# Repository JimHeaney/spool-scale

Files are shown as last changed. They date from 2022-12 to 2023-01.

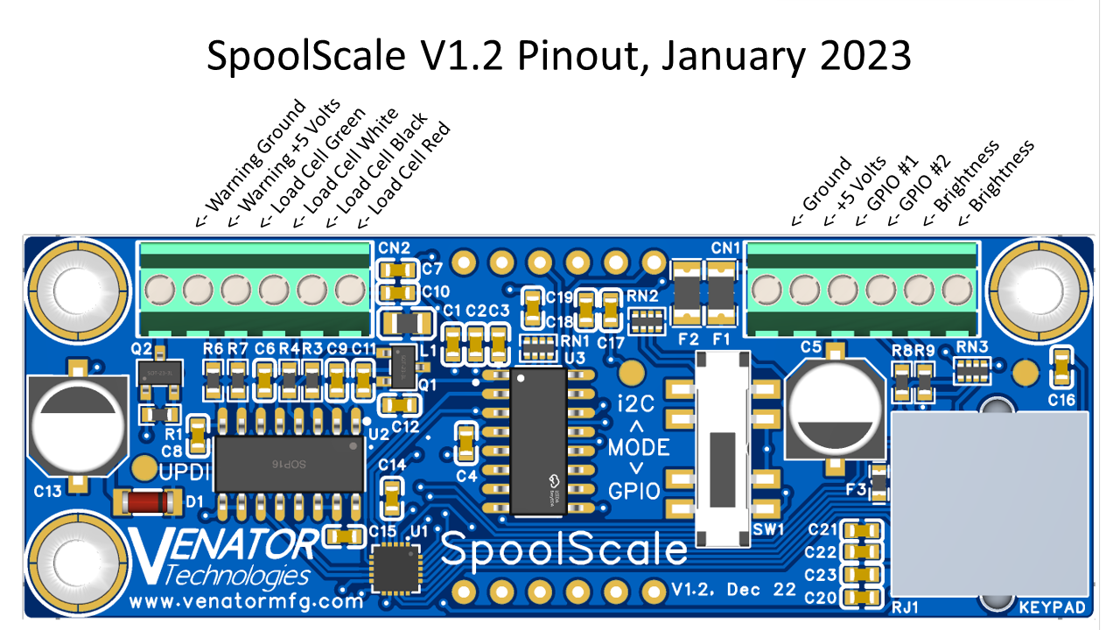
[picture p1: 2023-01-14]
Core/SpoolScale Pinout.png

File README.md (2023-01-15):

# SpoolScale

## Summary
Have you ever run out of filament mid-print? The SpoolScale is a simple add-on device for any 3D printer that allows you to precisely know how much filament is left on your spool. The SpoolScale can be integrated with any style 3D printer and spool holder, and can be connected to any wheatstone bridge load cell. Additional functionality can be unlocked by connecting the SpoolScale to a 3D printer directly via GPIO, i2C, or UART. 

### More information can be found on the [GitHub Wiki](https://github.com/JimHeaney/spool-scale/wiki).

## Current Release
There are no stable versions for release. The latest WIP is Version 1.1

## Current State
The SpoolScale is currently being developed to Version 1.2.

## What's New

[Read More on the Version Information page!](https://github.com/JimHeaney/spool-scale/wiki/Version-Information)

Version 1.2 will likely be the first stable release of the SpoolScale. Version 1.1 was used as a proof of concept and for small-scale field testing. A number of bugs were immediately identified, and a number of other improvements will be made based on user feedback. These include:
* Removing DIP switch configuration, instead adding RJ11 port for connecting an i2C keypad. 
  * This will allow for more versatile configuration, including typing in spool weights directly, saving/loading 4 "favorite" spool weights, etc. 
  * All of these settings will be exposed as i2C slave registers, so the keypad is not needed if using the SpoolScale as an i2C device. 
* Added more robust switch for selecting SpoolScale mode 
  * Removed UART mode, options are now GPIO, standalone, and i2C.
* Redid layout of PCB, removed secondary AtTiny footprint
* General component optimization, layout improvements, etc. 

Future Proposed Changes:
* Change 6P6C RJ12 to more common 6P4C RJ11 (remove plug detection)

## Instructions & Further Documentation
[See the wiki on GitHub!](https://github.com/JimHeaney/SpoolScale/wiki) 

## Photos & Media


## Support Me
You can buy me a coffee [here](https://www.buymeacoffee.com/jimheaney)!

## License
This project is licensed under the Creative Commons 4.0 Attribution-NonCommercial-ShareAlike. For more information, click [here](https://creativecommons.org/licenses/by-nc-sa/4.0/).

If you are interested in using this project under a different license (e.g. for commercial use), please contact me.

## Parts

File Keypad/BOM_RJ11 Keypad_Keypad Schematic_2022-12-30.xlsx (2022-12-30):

No. | Quantity | Device | Designator | Footprint | Value | Manufacturer Part | Manufacturer | Supplier Part | Supplier
1 | 2 | CC0603KRX7R9BB104 | C1,C3 | C0603 | 100nF | CC0603KRX7R9BB104 | YAGEO(国巨) | C14663 | LCSC
2 | 2 | CL10A106MA8NRNC | C2,C4 | C0603 | 10uF | CL10A106MA8NRNC | SAMSUNG(三星) | C96446 | LCSC
3 | 1 | BSMD0603-001-60V | F3 | F0603 |  | BSMD0603-001-60V | BHFUSE(佰宏) | C914088 | LCSC
4 | 1 | PH-00779 | H1 | HDR-TH_10P-P2.54-V-M |  | PH-00779 | Liansheng(连盛) | C2685184 | LCSC
5 | 2 | SMTSO3030CTJ | N1,N2 | SMD_BD5.6-D4.1 |  | SMTSO3030CTJ | Sinhoo(雄和远景) | C2915308 | LCSC
6 | 4 | 0603WAF2001T5E | R1,R2,R3,R4 | R0603 | 2kΩ | 0603WAF2001T5E | UNI-ROYAL(厚声) | C22975 | LCSC
7 | 1 | R-RJ11R06P-A801 | RJ1 | RJ11-TH_PCB-6P6C-90 |  | R-RJ11R06P-A801 | Ckmtw(灿科盟) | C189747 | LCSC
8 | 1 | 4D02WGJ0103TCE | RN1 | RES-ARRAY-SMD_0402-8P-L2.0-W1.0-BL | 10kΩ | 4D02WGJ0103TCE | UNI-ROYAL(厚声) | C25725 | LCSC
9 | 1 | PCA9557PW,118 | U1 | TSSOP-16_L5.0-W4.4-P0.65-LS6.4-BL |  | PCA9557PW,118 | NXP(恩智浦) | C141380 | LCSC

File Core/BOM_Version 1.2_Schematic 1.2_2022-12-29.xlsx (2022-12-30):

No. | Quantity | Device | Designator | Footprint | Value | Manufacturer Part | Manufacturer | Supplier Part | Supplier
1 | 3 | CL10C101JB8NNNC | C1,C2,C3 | C0603 | 100pF | CL10C101JB8NNNC | SAMSUNG(三星) | C14858 | LCSC
2 | 11 | CC0603KRX7R9BB104 | C4,C6,C7,C8,C9,C12,C14,C16,C18,C20,C22 | C0603 | 100nF | CC0603KRX7R9BB104 | YAGEO(国巨) | C14663 | LCSC
3 | 2 | VT1V101M0607 | C5,C13 | CAP-SMD_BD6.3-L6.6-W6.6-FD | 100uF | VT1V101M0607 | ROQANG(容强) | C141427 | LCSC
4 | 7 | CL10A106MA8NRNC | C10,C11,C15,C17,C19,C21,C23 | C0603 | 10uF | CL10A106MA8NRNC | SAMSUNG(三星) | C96446 | LCSC
5 | 2 | DB125-2.54-6P-GN | CN1,CN2 | CONN-TH_DB125-2.54-6P-GN |  | DB125-2.54-6P-GN | DIBO(地博电气) | C918124 | LCSC
6 | 1 | ZMM5V6-M | D1 | LL-34_L3.5-W1.5-RD |  | ZMM5V6-M | ST(先科) | C8062 | LCSC
7 | 2 | JK-nSMD100/16V | F1,F2 | F1206 |  | JK-nSMD100/16V | JK(金科) | C2830246 | LCSC
8 | 1 | BSMD0603-001-60V | F3 | F0603 |  | BSMD0603-001-60V | BHFUSE(佰宏) | C914088 | LCSC
9 | 1 | CMI201209U2R2KT | L1 | L0805 | 2.2uH | CMI201209U2R2KT | FH(风华) | C1043 | LCSC
10 | 1 | SR440801N/32 | LED1 | LED-SEG-TH_12P-L71.6-W25.7-P2.54-S22.00-BL |  | SR440801N/32 | 方舟 ARKLED | C252230 | LCSC
11 | 3 | SMTSO3030CTJ | N1,N2,N3 | SMD_BD5.6-D4.1 |  | SMTSO3030CTJ | Sinhoo(雄和远景) | C2915308 | LCSC
12 | 1 | S8550 | Q1 | SOT-23-3_L2.9-W1.6-P1.90-LS2.8-BR |  | S8550 | CJ（江苏长电/长晶） | C105432 | LCSC
13 | 1 | AO3400A_C20917 | Q2 | SOT-23-3_L2.9-W1.6-P1.90-LS2.8-BR |  | AO3400A | AOS | C20917 | LCSC
14 | 2 | 0603WAF2002T5E | R1,R3 | R0603 | 20kΩ | 0603WAF2002T5E | UNI-ROYAL(厚声) | C4184 | LCSC
15 | 1 | 0603WAF8201T5E | R4 | R0603 | 8.2kΩ | 0603WAF8201T5E | UNI-ROYAL(厚声) | C25981 | LCSC
16 | 2 | 0603WAF1000T5E | R6,R7 | R0603 |  | 0603WAF1000T5E | UNI-ROYAL(厚声) | C22775 | LCSC
17 | 2 | 0603WAF2200T5E | R8,R9 | R0603 |  | 0603WAF2200T5E | UNI-ROYAL(厚声) | C22962 | LCSC
18 | 1 | R-RJ11R06P-A801 | RJ1 | RJ11-TH_PCB-6P6C-90 |  | R-RJ11R06P-A801 | Ckmtw(灿科盟) | C189747 | LCSC
19 | 3 | 4D02WGJ0103TCE | RN1,RN2,RN3 | RES-ARRAY-SMD_0402-8P-L2.0-W1.0-BL | 10kΩ | 4D02WGJ0103TCE | UNI-ROYAL(厚声) | C25725 | LCSC
20 | 1 | K3-2336S-K1 | SW1 | SW-SMD_K3-2336S-K1 |  | K3-2336S-K1 | 韩国韩荣 | C145840 | LCSC
21 | 1 | ATTINY1616-MNR | U1 | QFN-20_L3.0-W3.0-P0.40-BL-EP1.7 |  | ATTINY1616-MNR | MICROCHIP(美国微芯) | C507118 | LCSC
22 | 1 | HX711 | U2 | SOP-16_L10.0-W3.9-P1.27-LS6.0-BL |  | HX711 | AVIA(海芯科技) | C43656 | LCSC
23 | 1 | TM1616 | U3 | SOIC-16_L9.9-W3.9-P1.27-LS6.0-BL |  | TM1616 | TM(天微) | C51000 | LCSC

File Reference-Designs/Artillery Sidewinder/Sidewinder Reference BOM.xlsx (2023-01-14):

SpoolScale Artillery Sidewinder X1 Reference Design
Bill of Materials, V1.1, Jan 2023
https://github.com/JimHeaney/spool-scale/wiki/Reference-Designs#artillery-sidewinder-x1
Number | Name | Quantity | Source | Link | Notes
1 | SpoolScale | 1 | Tindie | https://www.tindie.com/products/jimheaney/spoolscale/
2 | Load Cell - 5kg | 2 | Adafruit | https://www.adafruit.com/product/4541 | Can also be purchased with SpoolScale
3 | 4-Wire Cable | 1 | Amazon | https://www.amazon.com/gp/product/B08JTZCJV1/ref=ppx_yo_dt_b_search_asin_title?ie=UTF8&psc=1 | Need appx. 1 meter
4 | Interface Mount | 1 | Printed
5 | Load Cell Mount | 2 | Printed
6 | Load Cell Spacer | 4 | Printed
7 | Spool Mount Adapter | 2 | Printed
8 | Spool Spacer | 2 | Printed
9 | M4 T Nut | 4 | Amazon | https://www.amazon.com/gp/product/B07FPLZXTF/ref=ppx_yo_dt_b_search_asin_title?ie=UTF8&psc=1 | Large kit, can be used for other T-nuts
10 | M5 T Nut | 2 | Amazon | https://www.amazon.com/gp/product/B07FPLZXTF/ref=ppx_yo_dt_b_search_asin_title?ie=UTF8&psc=1 | Can be had from same kit as M4
11 | M5 Hex Nut | 4 | McMaster-Carr | https://www.mcmaster.com/90591A260/ | Can use M5 T Nuts instead
12 | M5x12 Countersunk | 2 | McMaster-Carr | https://www.mcmaster.com/91294A210/
13 | M5x18 Countersunk | 4 | McMaster-Carr | https://www.mcmaster.com/91294A213/
14 | M4x12 Socket Head | 4 | McMaster-Carr | https://www.mcmaster.com/91294A192/
15 | M4x12 Countersunk | 8 | McMaster-Carr | https://www.mcmaster.com/91294A192/
16 | M3x16 Countersunk | 3 | McMaster-Carr | https://www.mcmaster.com/91294A134/

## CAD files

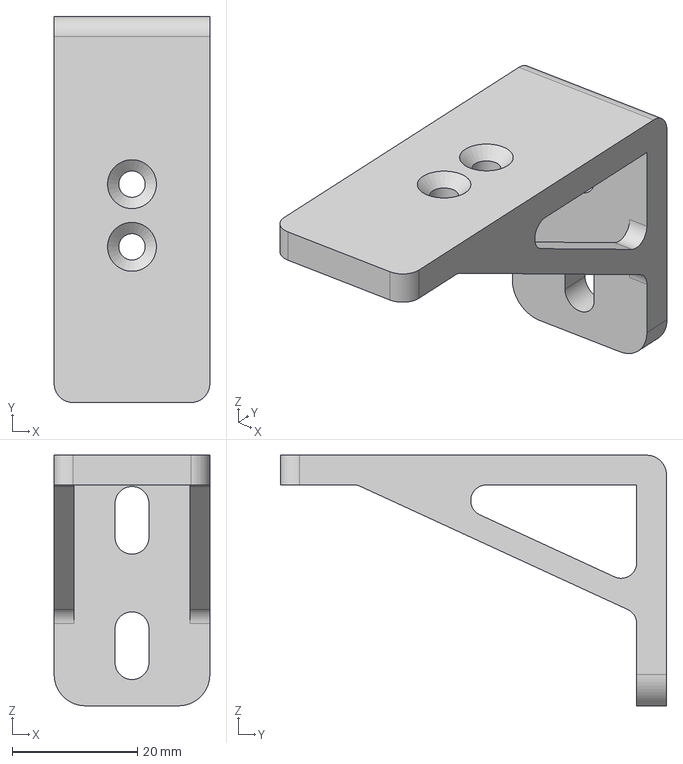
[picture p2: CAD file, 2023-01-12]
Reference-Designs/Artillery Sidewinder/Spool Mount Adapter.step
24.9 x 61.6 x 40.0 mm

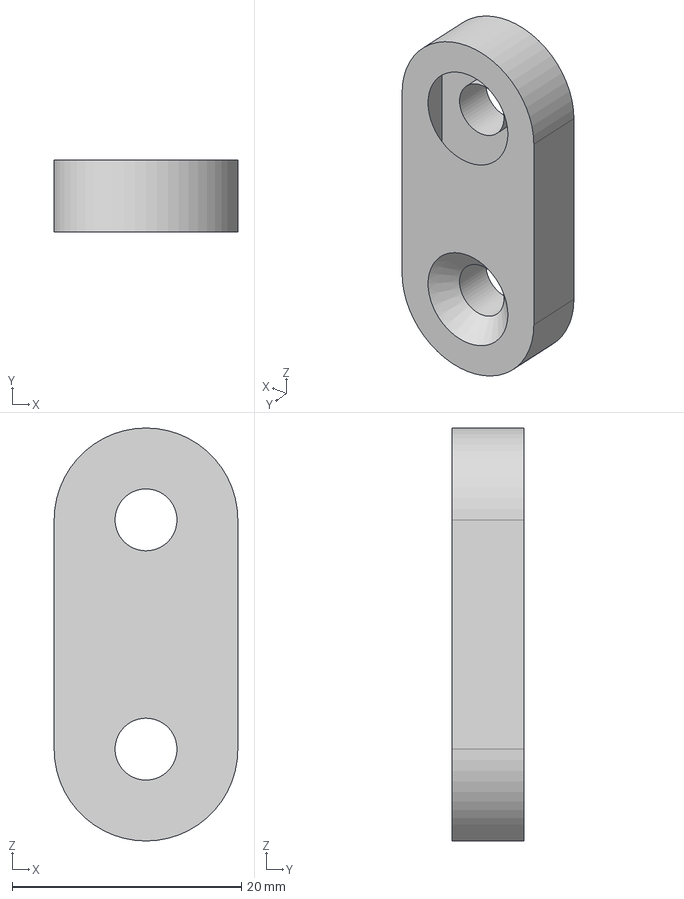
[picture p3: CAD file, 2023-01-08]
Reference-Designs/Artillery Sidewinder/Spool Spacer.step
16.0 x 6.25 x 36.0 mm

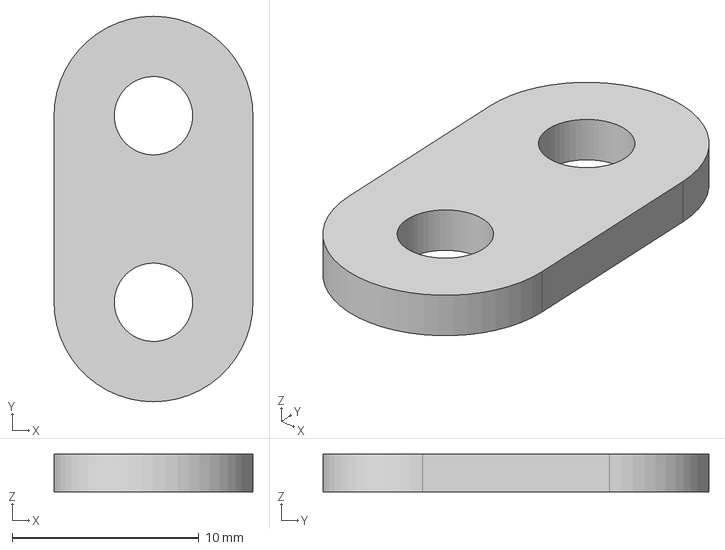
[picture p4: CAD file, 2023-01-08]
Reference-Designs/Artillery Sidewinder/Load Cell Spacer.step
10.7 x 20.7 x 2.03 mm

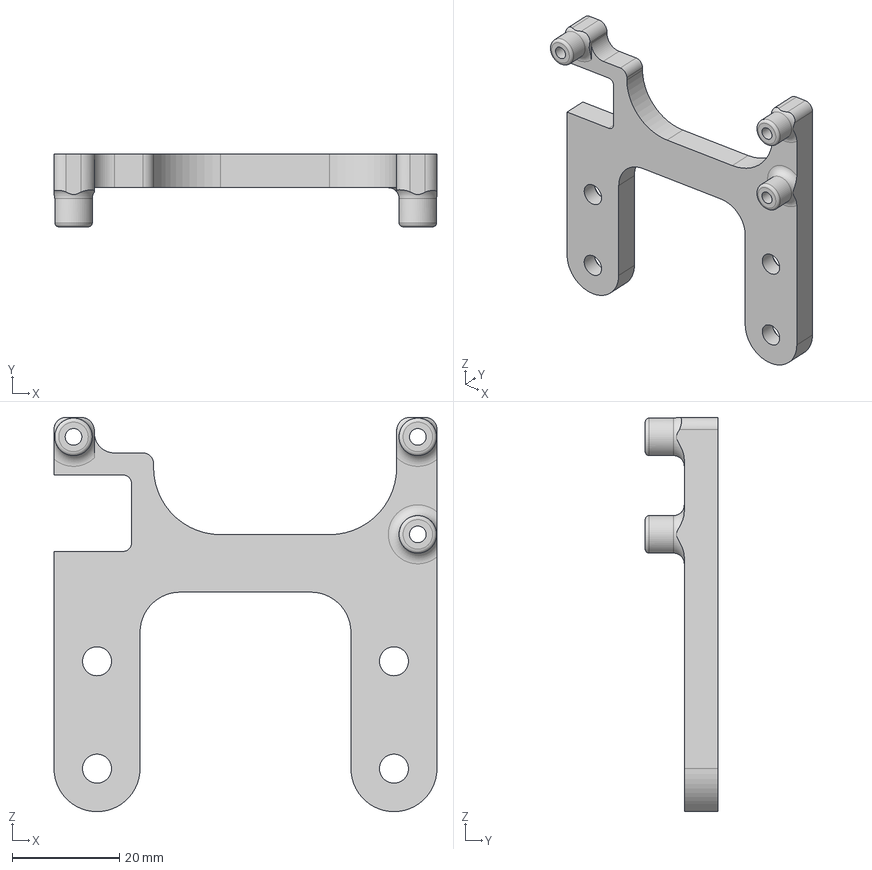
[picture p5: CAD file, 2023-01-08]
Reference-Designs/Artillery Sidewinder/Interface Mount.step
71.3 x 13.5 x 73.5 mm

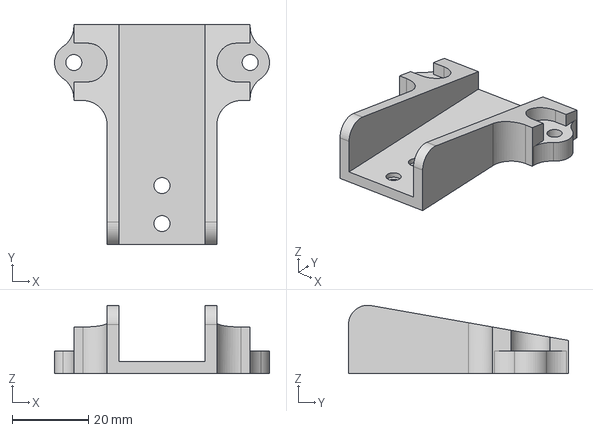
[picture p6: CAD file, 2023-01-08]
Reference-Designs/Artillery Sidewinder/Load Cell Mount.step
56.5 x 57.9 x 18.0 mm

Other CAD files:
Reference-Designs/Artillery Sidewinder/Interface Mount.3mf
Reference-Designs/Artillery Sidewinder/Load Cell Mount.3mf
Reference-Designs/Artillery Sidewinder/Load Cell Spacer.3mf
Reference-Designs/Artillery Sidewinder/Spool Mount Adapter.3mf
Reference-Designs/Artillery Sidewinder/Spool Spacer.3mf

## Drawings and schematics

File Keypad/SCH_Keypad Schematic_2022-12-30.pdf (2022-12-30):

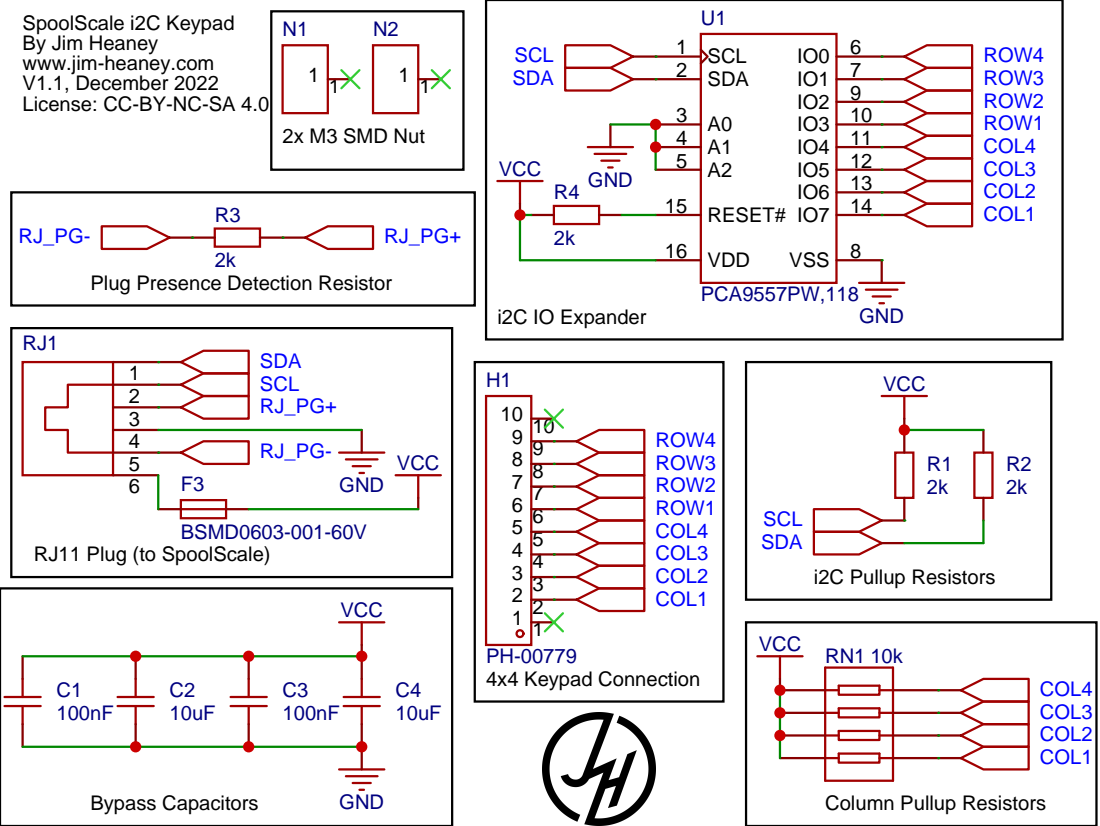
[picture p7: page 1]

SpoolScale i2C Keypad
By Jim Heaney
www.jim-heaney.com
V1.1, December 2022
License: CC-BY-NC-SA 4.0

Plug Presence Detection Resistor

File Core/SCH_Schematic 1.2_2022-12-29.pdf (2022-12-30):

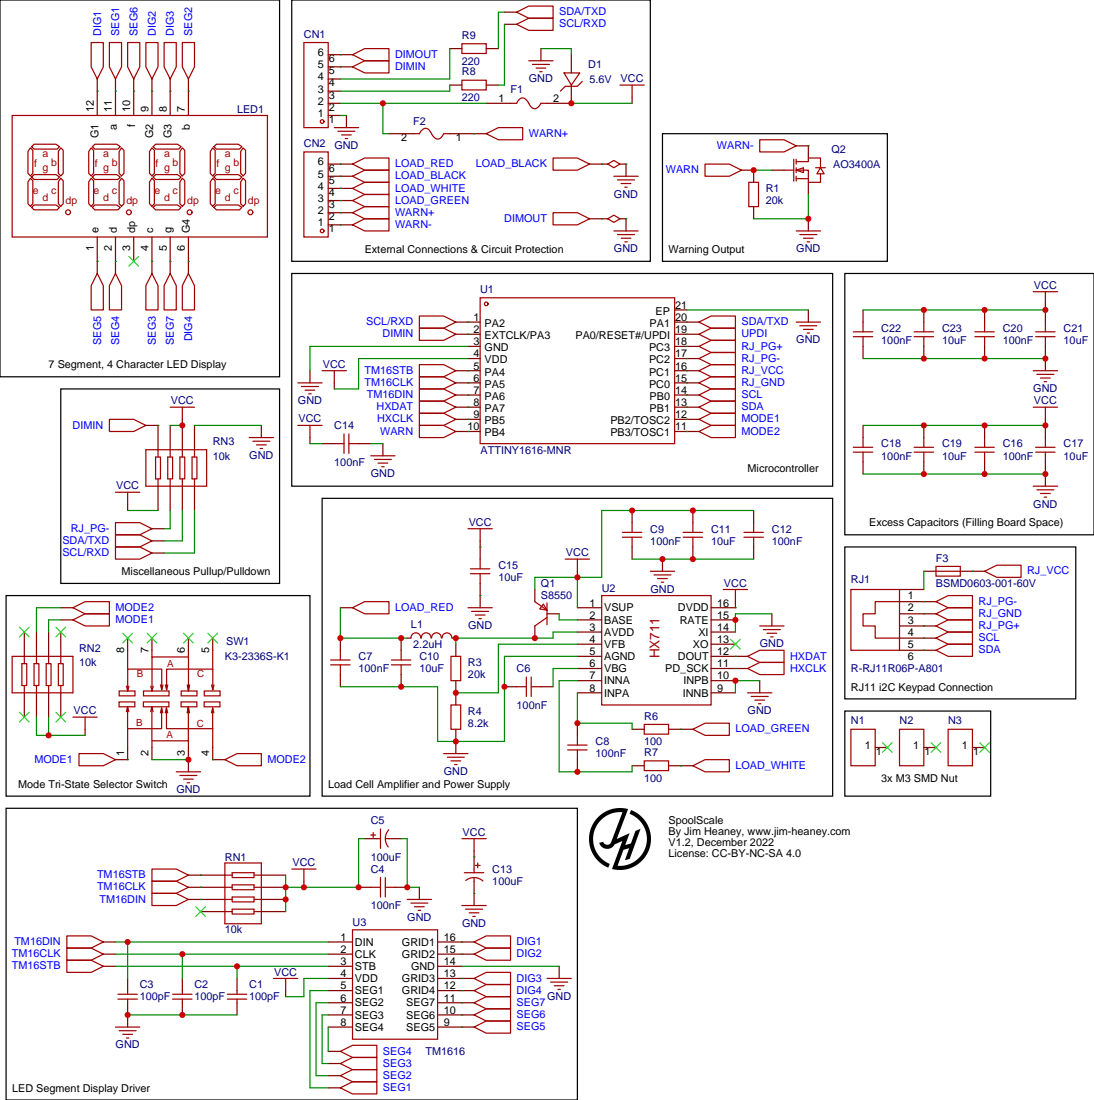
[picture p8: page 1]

7 Segment, 4 Character LED Display

Excess Capacitors (Filling Board Space)

GND
INPB 10 PD_SCK 11 DOUT 12 XO 13 XI 14 RATE 15 DVDD 16

Mode Tri-State Selector Switch

Load Cell Amplifier and Power Supply

SpoolScale
By Jim Heaney, www.jim-heaney.com
V1.2, December 2022
License: CC-BY-NC-SA 4.0

LED Segment Display Driver

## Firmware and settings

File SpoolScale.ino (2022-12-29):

//Spool Scale 
//Version 1.1.1
//By: Jim Heaney, www.jim-heaney.com
//December 2022

//GitHub: https://github.com/JimHeaney/spool-scale

//License: 
//Creative Commons 4.0 Attribution-NonCommercial-ShareAlike
//https://creativecommons.org/licenses/by-nc-sa/4.0/

//This version of the SpoolScale firmware is intended for use with the WIP release V1.1 of the hardware. 
//There were multiple bugs and shortcomings with the V1.1 hardware. This firmware is available solely for the purpose of documentation. 
//See V1.2 and beyond for a more useable version.

#define abs(x) ((x)>0?(x):-(x))

//Include Libraries:
#include <HX711.h>
#include <TM1616.h>
#include <TM16xxDisplay.h>
#include <EEPROM.h>

//Pin Names:
#define HX711_DAT PIN_PA4
#define HX711_CLK PIN_PA5
#define TM16_DAT PIN_PC1
#define TM16_CLK PIN_PC0
#define TM16_STB PIN_PC2
#define INTERFACE1 PIN_PA2
#define INTERFACE2 PIN_PA1
#define DIMIN PIN_PB0
#define WARN PIN_PA6
#define BUTTON PIN_PA7
#define DIP1 PIN_PB3
#define DIP2 PIN_PB2
#define DIP3 PIN_PB1
#define DIP4 PIN_PA3
#define DIP5 PIN_PC3
#define DIPR1 PIN_PB4
#define DIPR2 PIN_PB5

//Create Objects:
HX711 scale;
TM1616 module(TM16_DAT, TM16_CLK, TM16_STB);
TM16xxDisplay display(&module, 4);

//Variables:
int spool = 0; //The weight of an empty spool
int safety = 10; //A safety weight to subtract from the reading, to ensure we always show less filament than there actually is.
bool mode = 0; //The mode of the IO. Set to 1 i2C, 0 for GPIO.
float calibration = 0; //The calibratation value found in calibration routine or retrieved from EEPROM.
long zero = 0; //The output of the HX711 with nothing on it, found in calibration routint or retrieved from EEPROM
byte brightness = 0; //The current brigtness level of the screen. Stored globally to allow for some hysteresis
bool warnon = 0; //Set to 1 when the warning output is turned on
float warn = 50.0; //The number of grams to trigger the warning alarm. Currently hard-coded, may make a setting in the future.
float oldweight = 100000; //Stores the last measurement of the scale, to prevent jittering between 2 values. Starts very high so the code falls into start working.

void setup() {
  // put your setup code here, to run once:
  
  //Start scale and set pinModes:
  scale.begin(HX711_DAT, HX711_CLK);
  pinMode(WARN, OUTPUT);

  //Write "SPOL" then "SCLE" then "rxxx" (version number) to the screen during startup for a few seconds
  display.println("SPOL");
  delay(1000);
  display.println("SCLE");
  delay(1000);
  display.println("r111");
  delay(1000);
  display.println("");

  //Read in the values of all the setting switches
  //Due to a hardware issue, the DIP switches do not work. So instead, the weight of a hatchbox spool is hard-coded
  spool = 244;

  //Read if the button is held down on startup. If so, then run the calibration/reset routine by calling calibrate()
  if(digitalRead(BUTTON) == 1){
    calibrate();
  }
  
  //Load the calibration settings from EEPROM
  EEPROM.get(0, zero);
  EEPROM.get(10, calibration);
  scale.set_scale();
  scale.tare();
  scale.set_scale(calibration);
  scale.set_offset(zero);

  //Activate the proper communication standard based on the input switches
  //Hardware bugs mean this version will only support HIGH/LOW GPIO, so set to input pullup
  pinMode(INTERFACE1, INPUT_PULLUP);
  pinMode(INTERFACE2, INPUT_PULLUP);

}

void loop() {
  // put your main code here, to run repeatedly:

  //Read the states of the communication pins based on the mode
  //In GPIO mode, if the pins are low, just skip everything and turn the screen off
  if((digitalRead(INTERFACE1) == 0) || (digitalRead(INTERFACE2) == 0)){
    digitalWrite(WARN, 0);
    display.println("----");
    display.setIntensity(0);
    goto idle;
  }

  //Set the screen brightness:
  //Read the state of the DIMIN pin
  int brightin = analogRead(DIMIN);
  //If resistance connected is less than 1K (0.455V, 93), turn the display fully on
  if(brightin < 90){
    brightness = 7;  
  }
  //If resistance connected is between 1k (0.455V, 93) and 9k (2.368V, 483) (steps of 65), vary the brightness accordingly with some hysteresis
  if((brightin > 100) && (brightin < 165)){
    brightness = 6;
  }
  if((brightin > 175) && (brightin < 230)){
    brightness = 5;
  }
  if((brightin > 240) && (brightin < 285)){
    brightness = 4;
  }
  if((brightin > 295) && (brightin < 355)){
    brightness = 3;
  }
  if((brightin > 365) && (brightin < 420)){
    brightness = 2;
  }
  if((brightin > 430) && (brightin < 164805)){
    brightness = 1;
  }

  //If resistance connected is more than 9k (2.368V, 483) but less than 20k (3.333v, 680), turn the display fully off
  if((brightin > 490) && (brightin < 680)){
    brightness = 0;
  }
  //If resistance connected is more than 20k (3.333v, 680) (e.g. no connection), turn the display fully on
  if(brightin > 700){
    brightness = 7;
  }

  display.setIntensity(brightness);

  //Read the current scale weight, subtract spool weight
  float weight = scale.get_units(10);
  weight = weight - float(spool);

  //Subtract some extra "safety" weight to make sure that the scale never reads there is filament remaining when there isn't. 
  weight = weight - float(safety);
  
  //Stop the weight from going back up if the difference is just 1, to prevent jittering
  if((weight > oldweight) && ((weight - 1.0) <= oldweight)){
    weight = oldweight;
  } else{
    oldweight = weight;    
  }

  //If the weight is less than 0, just set the weight to 0
  if(weight <= 0.0){
    weight = 0.0;
  }

  //Report weight on the display
  display.println(weight,0);

  //If the weight is below the critical value, set the WARN pin high. 
  if((weight <= warn) && (warnon == 0)){
    warnon = 1;    
  }
  if((weight >= (warn + 10)) && (warnon == 1)){
    warnon = 0;
  }
  digitalWrite(WARN, warnon);

  idle:

  //Delay for a little bit (100ms?)
  delay(100);

}

void calibrate(){
  //Routine to run to calibrate the system

  //Write "CAL" on the screen
  display.println("CAL");
  //Wait until the button is released
  while(digitalRead(BUTTON) == 1){
    delay(1);    
  }
  //Wait another 1 second
  delay(1000);  
  
  //Write "PUT0" on the screen, indicating to put nothing on the spool holder
  display.println("PUT0");
  //Wait for button to be pressed
  while(digitalRead(BUTTON) == 0){
    delay(1);
  }
  //Once button is pressed, read in current scale weight as the 0 point of the scale
  scale.set_scale();
  scale.tare();
  zero = scale.read_average();
  
  //Write "ESPL" on the screen, indicating to put an empty spool on the scale 
  display.println("ESPL");  
  //Wait for the button to be pressed
  while(digitalRead(BUTTON) == 0){
    delay(1);
  }
  //Once button is pressed, enter into a loop to calibrate
  display.println("STby");
  unsigned long caltime = millis() + 120000; //Note the time and add 120 second. If calibration not done by then, error out. 
  bool calibrating = 1;
  float temp = scale.get_units(10); 
  calibration = temp / float(spool); //Start with a rough approximation of what the calibration value should be
  

  while(calibrating){
    scale.set_scale(calibration);
    temp = scale.get_units(10);
    float difference = temp - spool;
    if(abs(difference) <= 0.25){
      //If within 0.25 grams, mark as complete
      calibrating = 0;
      goto exitcal;
    }
    if(difference > 100.0){
      //If the weight is way outside the ok range and high, increase the calibration value by 10
      calibration = calibration + 10;
    }
    if(difference > 0.0){
      //If the weight is outside the ok range and high, increase the calibration value by 1
      calibration = calibration + 1;
    }
    if(difference < 0.0){
      //If the weight is less than 0, multiply calibration value by -1
      calibration = calibration * -1;
    }
    if(caltime <= millis()){
      //If a good value wasn't found in 60 seconds, error out.
      display.println("ERRO");
      delay(1000);
      display.println();
      calibrating = 0;
    }
    display.println(temp);
  }
  exitcal:
  EEPROM.put(0, zero);
  EEPROM.put(10, calibration);
  display.println("DONE");
  delay(1000);
  scale.set_scale(calibration);
  temp = scale.get_units(10);
  display.println(temp,0);
  delay(100);
  display.println("");
}

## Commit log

2022-12-29 Version 1.1 WIP Upload
    Upload of the Version 1.1 schematic and code. This are only here for documentation purposes, there are a number of bugs here that'll be rectified with hardware V1.2 and firmware V1.2.1.
    [SpoolScale.ino]
2022-12-30 Keypad initial commit
    [BOM_RJ11 Keypad_Keypad PCB_2022-12-29.xlsx]
2022-12-30 V1.2 Core Hardware Initial Commit
    [BOM_Version 1.2_Schematic 1.2_2022-12-29.xlsx]
2022-12-30 Added mounting holes to keypad PCB
    [BOM_RJ11 Keypad_Keypad Schematic_2022-12-30.xlsx]
2023-01-08 Added Sidewinder reference parts
    [Interface Mount.3mf, Interface Mount.step, Load Cell Mount.3mf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]
2023-01-08 Added BOM
    [Sidewinder Reference BOM.xlsx]
2023-01-12 Updated Sidewinder reference design
    [Spool Mount Adapter.3mf, Spool Mount Adapter.step]
2023-01-14 Updated Sidewinder BOM
    [Sidewinder Reference BOM.xlsx]
